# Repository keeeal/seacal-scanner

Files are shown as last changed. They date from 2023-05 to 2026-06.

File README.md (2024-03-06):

# SEACAL Scanner
A 3D printable photogrammetry scanner for the Southeast Asian Ceramics Archaeology Laboratory.





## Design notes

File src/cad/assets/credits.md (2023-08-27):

# axle-screw
 - Phil Barrenger (philbarrenger)
 - https://www.thingiverse.com/thing:1657541
# phone-clamp
 - Ryan Huang (HeyVye)
 - https://www.thingiverse.com/thing:4619937
# gopro-bolt
 - Ryan Huang (HeyVye)
 - https://www.thingiverse.com/thing:3774977

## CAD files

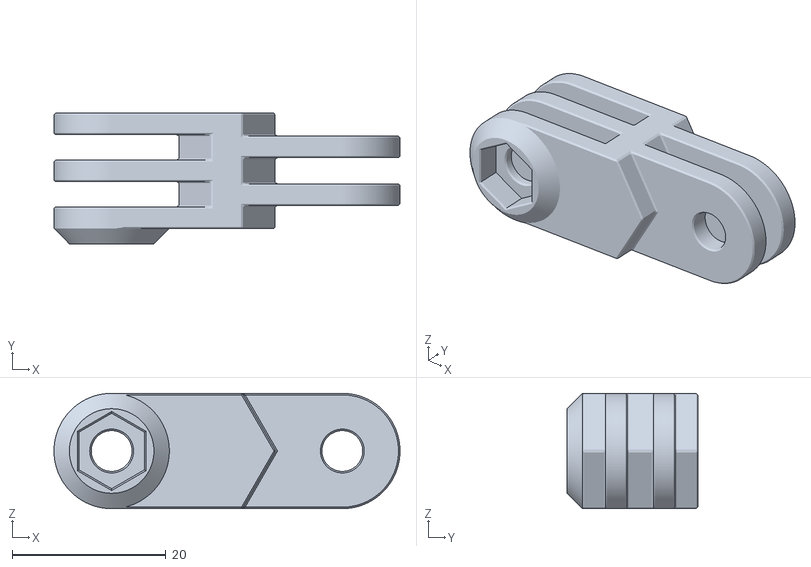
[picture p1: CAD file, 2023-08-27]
src/cad/assets/phone-clamp/clamp-extender.stl
45.0 x 17.0 x 15.0

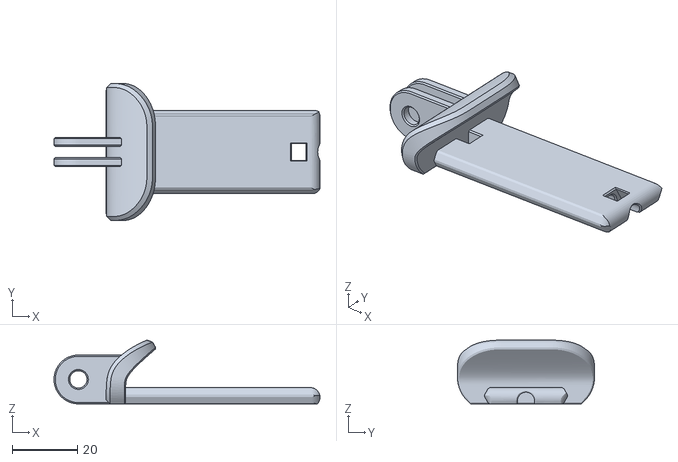
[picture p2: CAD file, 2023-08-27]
src/cad/assets/phone-clamp/clamp-b.stl
81.5 x 42.0 x 19.6

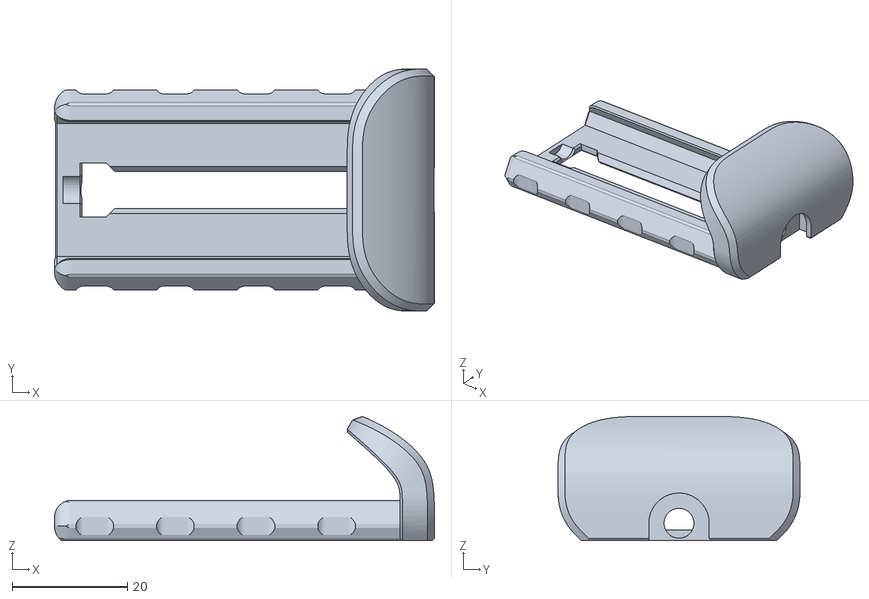
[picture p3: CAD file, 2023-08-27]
src/cad/assets/phone-clamp/clamp-a.stl
66.0 x 42.0 x 21.6

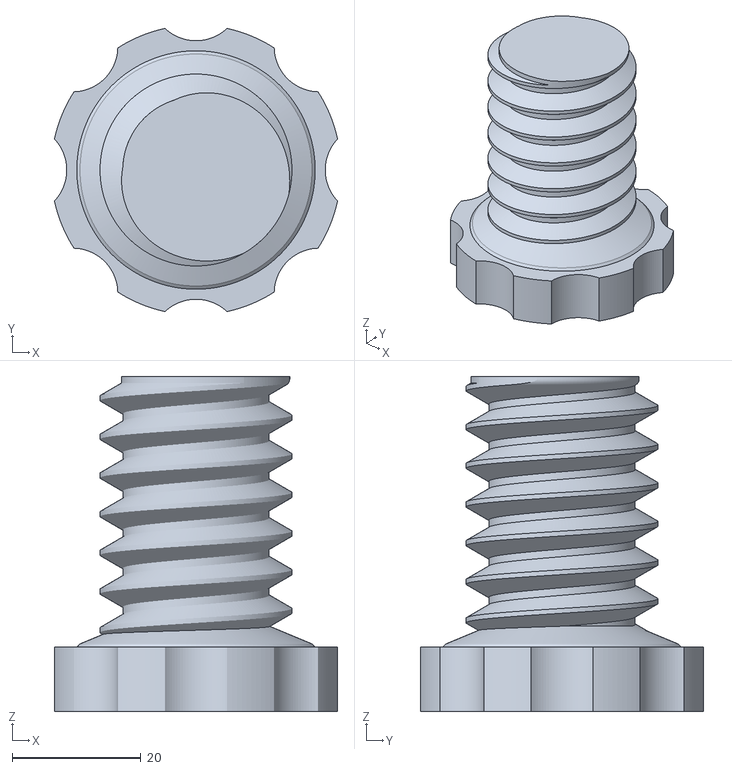
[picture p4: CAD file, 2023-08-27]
src/cad/assets/axle-screw.stl
44.0 x 44.0 x 52.0

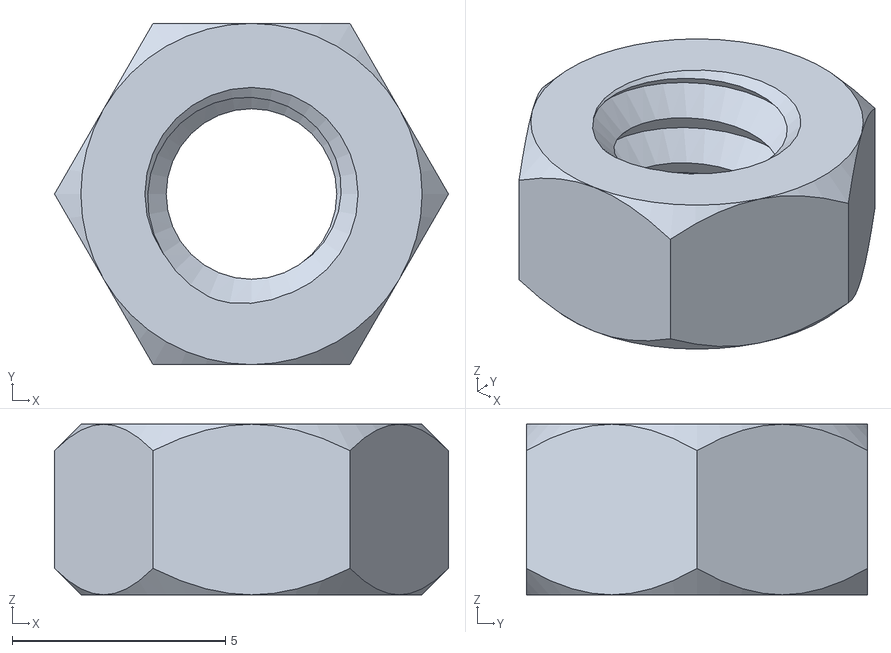
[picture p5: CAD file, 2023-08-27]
src/cad/assets/gopro-bolt/gopro-nut.stl
9.24 x 8.00 x 4.00

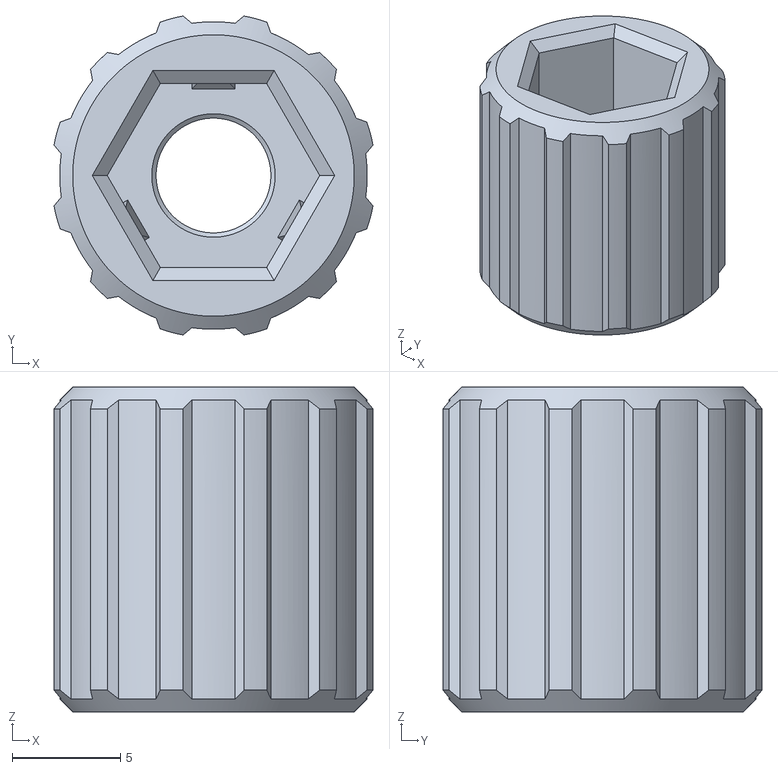
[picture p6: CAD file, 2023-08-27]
src/cad/assets/gopro-bolt/gopro-knob.stl
14.7 x 14.7 x 15.0

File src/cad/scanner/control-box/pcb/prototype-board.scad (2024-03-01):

use <../../../utils/shapes/2d/rounded-square.scad>
use <dupont.scad>

EPS = 1e-3;

module prototype_board()
{
    color([ 0.4, 0.1, 0.1 ]) linear_extrude(1.5)
    {
        rounded_square([ 66, 53.5 ], r = 1, center = true, $fn = 4);
        translate([ 33, -4 ]) rounded_square([ 5 + EPS, 39 ], r = 2.5, center = true, $fn = 4);
    }
}

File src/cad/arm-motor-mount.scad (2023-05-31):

// clang-format off

use <utils/shapes/2d/rounded-square.scad>

$fn = 32;

// clang-format on

module tube_mount()
{
    difference()
    {
        union()
        {
            linear_extrude(47, center = true) rounded_square(30.2, r = 1.8, center = true);
            translate([ -30.2 / 4, 0, 0 ]) linear_extrude(47, center = true) square([ 30.2 / 2, 30.2 ], center = true);
        }

        linear_extrude(62, center = true) rounded_square(27, r = 1, center = true);
    }
    for (n = [-1:1])
        translate([ 0, 0, n * 12 ]) for (i = [0:3]) rotate(90 * i) hull()
        {
            translate([ -5, 14, -4 ]) sphere(0.5);
            translate([ 5, 14, -4 ]) sphere(0.5);
            translate([ -5, 13.2, 0 ]) sphere(0.5);
            translate([ 5, 13.2, 0 ]) sphere(0.5);
            translate([ -5, 14, +4 ]) sphere(0.5);
            translate([ 5, 14, +4 ]) sphere(0.5);
        }
}

module nema_mount()
{
    difference()
    {
        translate([ 0, 0, 0 ]) linear_extrude(30.2) union()
        {
            rounded_square([ 47, 47 ], r = 4, center = true, $fn = 4);
            translate([ 0, -47 / 4 ]) square([ 47, 47 / 2 ], center = true);
        }
        translate([ 0, 0, -2 ]) linear_extrude(30.2) rounded_square([ 43, 43 ], r = 5, center = true);
        translate([ 0, 0, -1 ]) cylinder(100, r = 12);
        for (i = [ 0, 1, 2, 3 ])
            rotate([ 0, 0, i * 90 ]) translate([ 31.04 / 2, 31.04 / 2, 0 ]) cylinder(100, d = 4);
    }
}

module arm_motor_mount()
{
    rotate([ 0, 90, 0 ]) tube_mount();
    difference()
    {
        translate([ 0, 15.1, 38.5 ]) rotate([ 90, 0, 0 ]) nema_mount();
        translate([ 0, 15, 38.5 ]) cube([ 100, 16, 18 ], center = true);
    }
}

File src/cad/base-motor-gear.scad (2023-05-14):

// clang-format off
use <utils/gears/herringbone.scad>
use <utils/gears/simple.scad>

$fn = 32;
// clang-format on

module base_motor_gear(tol_x = .2, tol_z = .4)
{
    difference()
    {
        union()
        {
            herringbone_gear(10, 12, -32);
            cylinder(20, r = 5);
        }
        translate([ 0, 0, -1 ]) linear_extrude(100) difference()
        {
            circle(2.5 + tol_x);
            translate([ 7 + tol_x, 0 ]) square([ 10, 10 ], true);
        }
    }
}

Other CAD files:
src/cad/assets/phone-clamp/clamp-nut.stl
src/cad/parts/arm-motor-mount.scad
src/cad/__assembly__.scad
src/cad/apex.scad
src/cad/axle.scad
src/cad/badge.scad
src/cad/base.scad
src/cad/bearing-gear.scad
src/cad/cap.scad
src/cad/components/aluminium-tube.scad
src/cad/components/stop-button.scad
src/cad/corner.scad
src/cad/foot.scad
src/cad/gopro-mount.scad
src/cad/parts/apex.scad
src/cad/parts/axle.scad
src/cad/parts/badge.scad
src/cad/parts/base-motor-gear.scad
src/cad/parts/base.scad
src/cad/parts/bearing-gear.scad
src/cad/parts/foot.scad
src/cad/parts/gopro-mount.scad
src/cad/scanner/__subassembly__.scad
src/cad/scanner/arm/aluminium-tube.scad
src/cad/scanner/arm/axle.scad
src/cad/scanner/arm/gopro-mount.scad
src/cad/scanner/control-box/__subassembly__.scad
src/cad/scanner/control-box/box/__subassembly__.scad
src/cad/scanner/control-box/box/box-without-components.scad
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

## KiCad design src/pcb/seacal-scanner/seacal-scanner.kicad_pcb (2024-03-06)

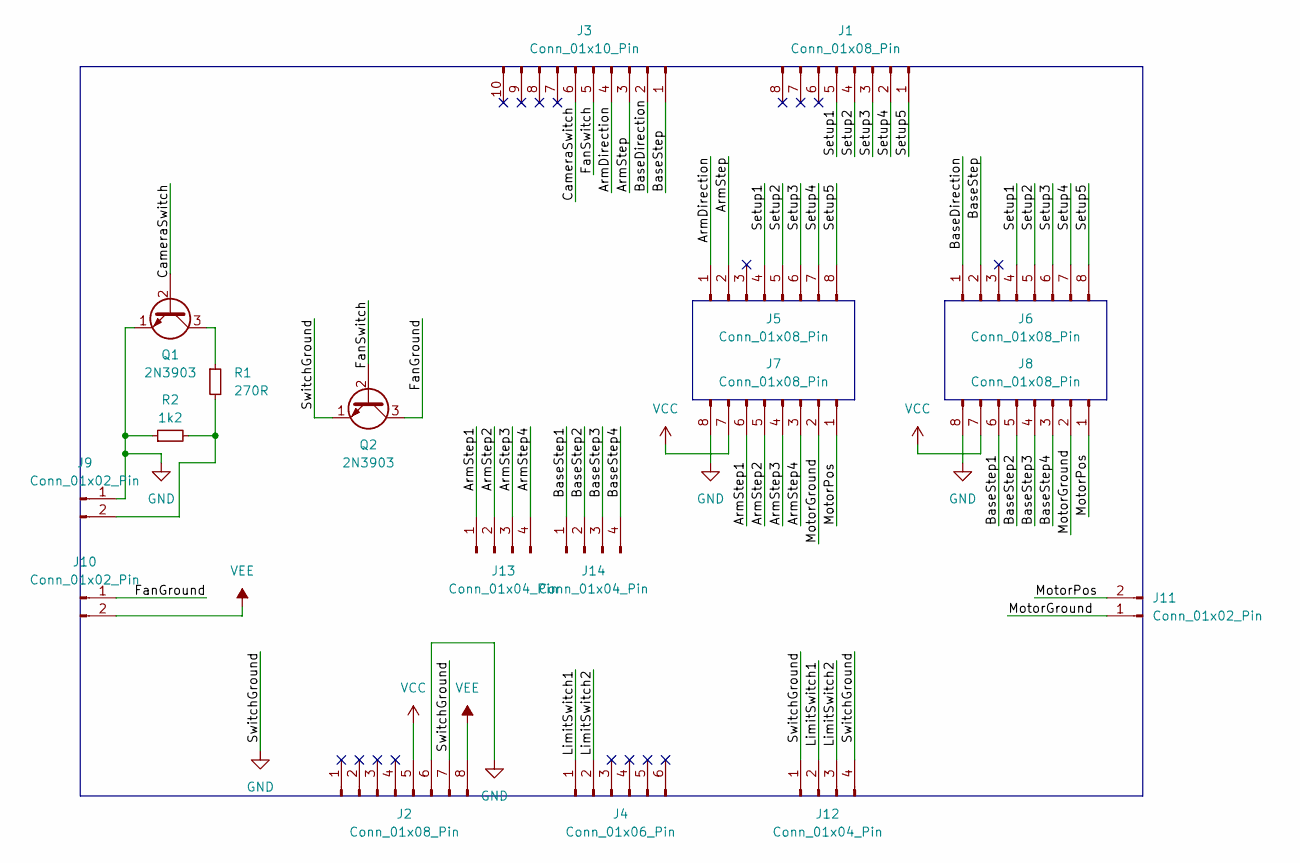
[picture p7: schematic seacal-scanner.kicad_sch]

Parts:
J1, J2, J5, J6, J7, J8: Conn_01x08_Pin; PinHeader_1x08_P2.54mm_Vertical
J3: Conn_01x10_Pin; PinHeader_1x10_P2.54mm_Vertical
J4: Conn_01x06_Pin; PinHeader_1x06_P2.54mm_Vertical
J9, J10, J11: Conn_01x02_Pin; PinHeader_1x02_P2.54mm_Vertical
J12, J13, J14: Conn_01x04_Pin; PinHeader_1x04_P2.54mm_Vertical
Q1, Q2: 2N3903; TO-92_Inline
R1: 270R; R_Axial_DIN0207_L6.3mm_D2.5mm_P10.16mm_Horizontal
R2: 1k2; R_Axial_DIN0207_L6.3mm_D2.5mm_P10.16mm_Horizontal

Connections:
/ArmDirection: J3.4, J5.1
/ArmStep: J3.3, J5.2
/ArmStep1: J7.6, J13.1
/ArmStep2: J7.5, J13.2
/ArmStep3: J7.4, J13.3
/ArmStep4: J7.3, J13.4
/BaseDirection: J3.2, J6.1
/BaseStep: J3.1, J6.2
/BaseStep1: J8.6, J14.1
/BaseStep2: J8.5, J14.2
/BaseStep3: J8.4, J14.3
/BaseStep4: J8.3, J14.4
/CameraSwitch: J3.6, Q1.2 (B)
/FanGround: J10.1, Q2.3 (C)
/FanSwitch: J3.5, Q2.2 (B)
/LimitSwitch1: J4.1, J12.2
/LimitSwitch2: J4.2, J12.3
/MotorGround: J7.2, J8.2, J11.1
/MotorPos: J7.1, J8.1, J11.2
/Setup1: J1.5, J5.4, J6.4
/Setup2: J1.4, J5.5, J6.5
/Setup3: J1.3, J5.6, J6.6
/Setup4: J1.2, J5.7, J6.7
/Setup5: J1.1, J5.8, J6.8
GND: J2.6, J2.7, J7.8, J8.8, J9.1, J12.1, J12.4, Q1.1 (E), Q2.1 (E), R2.1
unnamed: J9.2, R1.2, R2.2
unnamed: Q1.3 (C), R1.1
VCC: J2.5, J7.7, J8.7
VEE: J2.8, J10.2

Board: 2 copper layers, 18 parts (0 on the bottom side), 29 nets, no tracks yet.

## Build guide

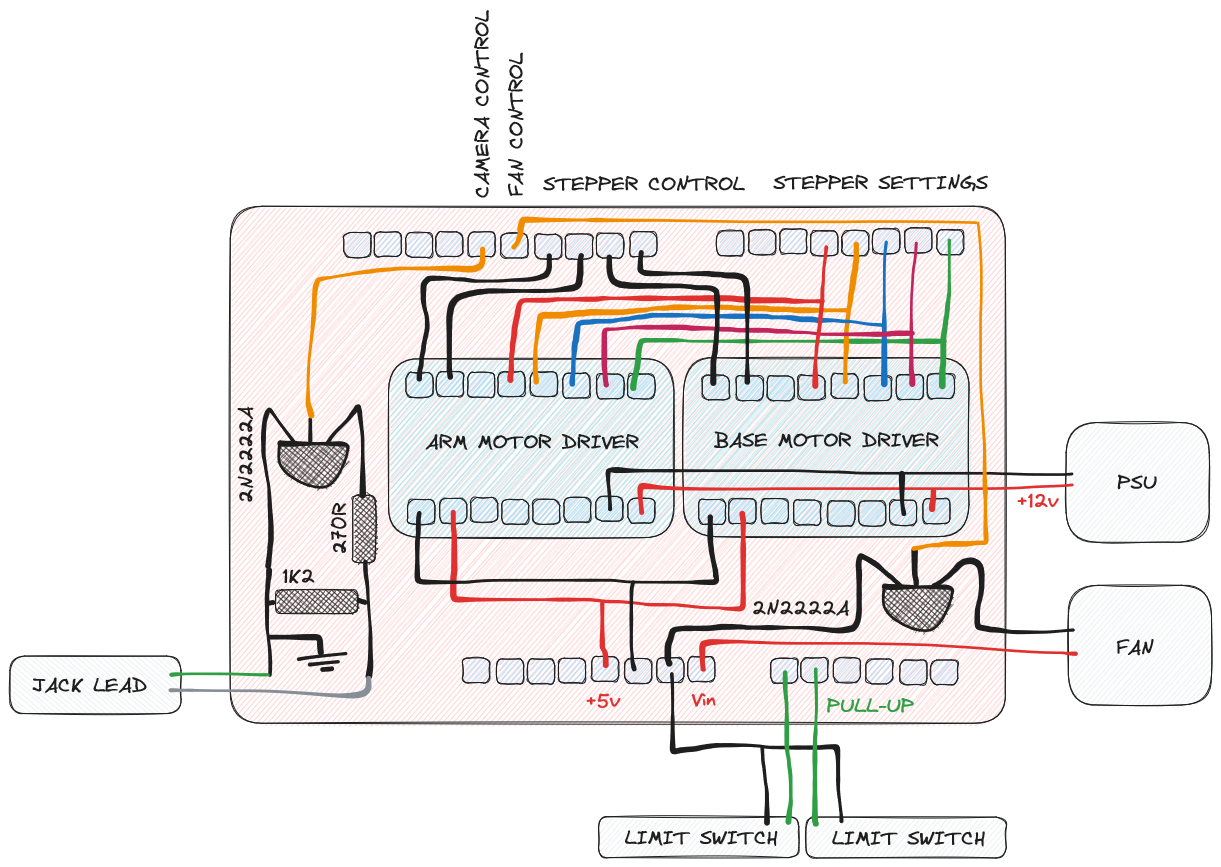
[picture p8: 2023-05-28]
assets/wiring-diagram/wiring-diagram.png

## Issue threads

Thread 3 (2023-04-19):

Design camera arm joints

keeeal, 2023-04-19:
Blocked by #15

Includes
 - basic push-fit joints
 - joints with legs
 - swivel joints at apex

Closed 2023-04-28.

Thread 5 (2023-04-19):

Add smooth acceleration option to stepper motor control

keeeal, 2023-04-19:
Blocked by #11

keeeal, 2023-04-30:
https://docs.arduino.cc/learn/electronics/stepper-motors Use Stepper.h instead of writing speed logic from scratch.

keeeal, 2023-05-03:
https://youtu.be/jsXolwJskKM motion filtering

keeeal, 2023-05-03:
https://learn.adafruit.com/multi-tasking-the-arduino-part-1/overview Do not use delays

keeeal, 2023-05-13:
www.airspayce.com/mikem/arduino/AccelStepper/ There is a library for this

Closed 2023-08-27.

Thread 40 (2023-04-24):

Replace firmware workflow with docker image

keeeal, 2023-04-24:
Docker image must contain `arduino-cli`. This will allow local reproducible builds.

Also make firmware the default make target.

Closed 2023-04-24.

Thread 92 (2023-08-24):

Extend feet to accomodate arm

keeeal, 2023-08-24:
- Arm collides with frame when at its lowest point
- Frame must be narrower

=> redesign feet to allow frame to push into them further

Closed 2023-08-27.

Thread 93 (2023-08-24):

Grip arm in axle better

keeeal, 2023-08-24:
- arm slides in push fit axle piece
- push fit is tight enough at first but seems to loosen over time

=> add threaded hole and large printed bolt... or something better?

Closed 2023-08-27.

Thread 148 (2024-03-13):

Fix driver footprints

keeeal, 2024-03-13:

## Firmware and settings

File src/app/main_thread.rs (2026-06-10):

use std::collections::VecDeque;
use std::env::consts::OS;
use std::path::Path;
use std::sync::mpsc::channel;
use std::sync::mpsc::TryRecvError;
use std::sync::{Arc, Mutex};
use std::thread;
use std::time::Duration;

use eframe::egui;

use crate::camera;
use crate::camera::Camera;
use crate::message::Message;
use crate::{read_thread, write_thread};
use crate::{CaptureState, LogLevel, State};

const SERIAL_BAUD: u32 = 115200;

// #[derive(Debug, Clone)]
struct Position {
    index: u32,
    base: f64,
    arm: f64,
    photo: bool,
}

impl Position {
    fn to_scanner_coordinates(&self) -> (u32, u32) {
        ((self.base * 1024.) as u32, (self.arm * 1024.) as u32)
    }

    fn to_degrees(&self) -> (f64, f64) {
        ((self.base * 360.) % 360., (self.arm * 150.) - 60.)
    }
}

fn generate_positions(
    num_photos: u32,
    num_revolutions: f64,
    spiral_pattern: bool,
    start_height: f64,
    stop_height: f64,
) -> Vec<Position> {
    if num_photos == 0 {
        return Vec::new();
    }
    let mut positions = Vec::new();
    for index in 0..num_photos {
        let mut fraction = (index + 1) as f64 / num_photos as f64;
        let base_position = fraction * num_revolutions;
        if !spiral_pattern {
            fraction = base_position.floor() / num_revolutions;
        }
        let arm_position = fraction * (stop_height - start_height) + start_height;
        positions.push(Position {
            index,
            base: base_position,
            arm: arm_position,
            photo: true,
        });
    }
    positions.push(Position {
        index: num_photos,
        base: positions.last().unwrap().base,
        arm: 0.,
        photo: false,
    });
    positions
}

pub fn spawn(state: Arc<Mutex<State>>, context: egui::Context) {
    let log = |level: LogLevel, message: String| {
        state.lock().unwrap().log(level, message);
        context.request_repaint();
    };
    let log_if_quiet_for = |duration: Duration, level: LogLevel, message: String| {
        state
            .lock()
            .unwrap()
            .log_if_quiet_for(duration, level, message);
        context.request_repaint();
    };

    let port_prefix = if OS == "windows" {
        "COM"
    } else if OS == "linux" {
        "/dev/ttyACM"
    } else {
        panic!("Unsupported OS");
    };

    let read_port = Arc::new(Mutex::new(None));
    let write_port = Arc::new(Mutex::new(None));
    let read_port_clone = read_port.clone();
    let write_port_clone = write_port.clone();
    let (read_sender, read_receiver) = channel::<Message>();
    let (write_sender, write_receiver) = channel::<Message>();
    thread::spawn(|| read_thread::spawn(read_port_clone, read_sender));
    thread::spawn(|| write_thread::spawn(write_port_clone, write_receiver));

    let mut last_arm_speed: u8 = 100;
    let mut last_base_speed: u8 = 100;
    let mut move_to = |coordinates: (u32, u32)| {
        let arm_speed = state.lock().unwrap().arm_speed;
        let base_speed = state.lock().unwrap().base_speed;
        if arm_speed != last_arm_speed || base_speed != last_base_speed {
            write_sender
                .send(Message::SetSpeed((base_speed, arm_speed)))
                .unwrap();
            last_arm_speed = arm_speed;
            last_base_speed = base_speed;
            println!("Set speed to ({}, {})", base_speed, arm_speed);
            thread::sleep(Duration::from_millis(100));
        }
        write_sender.send(Message::MoveTo(coordinates)).unwrap();
    };

    let mut camera: Option<Camera> = None;
    let mut position_queue: VecDeque<Position> = VecDeque::new();
    let mut object_directory: Option<String> = None;

    loop {
        if state.lock().unwrap().refresh_clicked {
            state.lock().unwrap().refresh_clicked = false;
            match camera::list() {
                Ok(cameras) => state.lock().unwrap().all_cameras = cameras,
                Err(error) => state
                    .lock()
                    .unwrap()
                    .log(LogLevel::Error, format!("{}", error)),
            }
        }
        if state.lock().unwrap().test_clicked {
            state.lock().unwrap().test_clicked = false;
            let selected_camera = state.lock().unwrap().selected_camera.clone();
            camera = match camera::setup(selected_camera) {
                Ok(camera) => Some(camera),
                Err(error) => {
                    log(LogLevel::Error, format!("{}", error));
                    continue;
                }
            };
            if let Some(ref mut camera) = camera {
                let save_directory = state.lock().unwrap().save_directory.clone();
                let path = format!("{}/TEST.jpg", save_directory.to_str().unwrap());
                match camera::save_photo(camera, Path::new(&path)) {
                    Ok(buffer) => log(
                        LogLevel::Success,
                        format!("Saved to {} ({})", path, buffer.resolution()),
                    ),
                    Err(error) => log(LogLevel::Error, format!("{}", error)),
                }
            }
        }
        if read_port.lock().unwrap().is_none() || write_port.lock().unwrap().is_none() {
            *read_port.lock().unwrap() = None;
            *write_port.lock().unwrap() = None;

            log_if_quiet_for(
                Duration::from_secs(2),
                LogLevel::Warning,
                "Searching for device".to_string(),
            );
            let ports = serialport::available_ports().unwrap_or_default();
            for info in ports {
                if !info.port_name.starts_with(port_prefix) {
                    continue;
                }
                let port = match serialport::new(&info.port_name, SERIAL_BAUD)
                    .dtr_on_open(true)
                    .timeout(Duration::from_millis(10))
                    .open()
                {
                    Ok(port) => port,
                    Err(_) => continue,
                };
                match port.clear(serialport::ClearBuffer::All) {
                    Ok(()) => {}
                    Err(_) => {
                        continue;
                    }
                }
                *read_port.lock().unwrap() = Some(port.try_clone().unwrap());
                *write_port.lock().unwrap() = Some(port);

                // Ping the device and wait for a pong response
                write_sender.send(Message::Ping).unwrap();
                match read_receiver.recv_timeout(Duration::from_secs(1)) {
                    Ok(Message::Pong) => {
                        log(LogLevel::Success, "Connected".to_string());
                        continue;
                    }
                    _ => {
                        *read_port.lock().unwrap() = None;
                        *write_port.lock().unwrap() = None;
                        continue;
                    }
                }
            }
            thread::sleep(Duration::from_millis(100));
        } else {
            match read_receiver.try_recv() {
                Ok(Message::MoveComplete(reported_coordinates)) => {
                    println!("Scanner is at {:?}", reported_coordinates);
                    if position_queue.front().is_none() {
                        log(
                            LogLevel::Warning,
                            format!("Unexpected position: {:?}", reported_coordinates),
                        );
                        continue;
                    }
                    let current_position = position_queue.front().unwrap();
                    let current_coordinates = current_position.to_scanner_coordinates();
                    if reported_coordinates != current_coordinates {
                        log(
                            LogLevel::Warning,
                            format!(
                                "Expected position {:?}, got {:?}",
                                current_coordinates, reported_coordinates
                            ),
                        );
                        if state.lock().unwrap().capture_state != CaptureState::Paused {
                            move_to(current_coordinates);
                        }
                        continue;
                    }
                    if current_position.photo {
                        let (base_degrees, arm_degrees) = current_position.to_degrees();
                        if let Some(ref mut camera) = camera {
                            let save_directory = state.lock().unwrap().save_directory.clone();
                            let object_name = state.lock().unwrap().object_name.clone();
                            let photos_per_position = state.lock().unwrap().photos_per_position;
                            let shutter_delay = state.lock().unwrap().shutter_delay;
                            if object_directory.is_none() {
                                object_directory = Some(
                                    format!("{}/{}", save_directory.to_str().unwrap(), object_name)
                                        .to_string(),
                                )
                            }
                            for index in 0..photos_per_position {
                                thread::sleep(Duration::from_millis(shutter_delay as u64));
                                let path = format!(
                                    "{}/{}_{:.1}deg_{:.1}deg{}.jpg",
                                    object_directory.as_ref().unwrap(),
                                    current_position.index,
                                    base_degrees,
                                    arm_degrees,
                                    if photos_per_position > 1 {
                                        format!(".{}", index + 1)
                                    } else {
                                        "".to_string()
                                    }
                                );
                                match camera::save_photo(camera, Path::new(&path)) {
                                    Ok(buffer) => log(
                                        LogLevel::Success,
                                        format!("Saved to {} ({})", path, buffer.resolution()),
                                    ),
                                    Err(error) => log(LogLevel::Error, format!("{}", error)),
                                }
                            }
                        }
                    }
                    state.lock().unwrap().progress = (current_position.index + 1) as f32
                        / (position_queue.back().unwrap().index + 1) as f32;
                    position_queue.pop_front();
                    if let Some(next_position) = position_queue.front() {
                        if state.lock().unwrap().capture_state != CaptureState::Paused {
                            move_to(next_position.to_scanner_coordinates());
                        }
                    } else {
                        write_sender.send(Message::DisableSteppers).unwrap();
                        object_directory = None;
                        state.lock().unwrap().capture_state = CaptureState::Idle;
                    }
                    context.request_repaint();
                }
                Ok(Message::StartPressed) => {
                    state.lock().unwrap().capture_clicked = true;
                }
                Ok(Message::StopPressed) => {
                    log(LogLevel::Error, "Emergency stop activated".to_string());
                    position_queue.clear();
                    state.lock().unwrap().capture_state = CaptureState::Stopped;
                    state.lock().unwrap().progress = 0.;
                    context.request_repaint();
                }
                Ok(Message::StopReleased) => {
                    log(LogLevel::Info, "Emergency stop released".to_string());
                    position_queue.clear();
                    state.lock().unwrap().capture_state = CaptureState::Idle;
                    state.lock().unwrap().progress = 0.;
                    context.request_repaint();
                }
                Ok(Message::HomingInProgress) => {
                    log(LogLevel::Info, "Homing in progress".to_string())
                }
                Ok(Message::HomingError) => log(LogLevel::Error, "Homing Error".to_string()),
                Ok(Message::UnexpectedMsg(discriminant)) => log(
                    LogLevel::Warning,
                    format!("[CTRL] Unexpected message: {:X}", discriminant),
                ),
                Ok(message) => log(
                    LogLevel::Warning,
                    format!("[APP] Unexpected message: {:?}", message),
                ),
                Err(TryRecvError::Disconnected) => {
                    *read_port.lock().unwrap() = None;
                    *write_port.lock().unwrap() = None;
                    continue;
                }
                Err(TryRecvError::Empty) => {}
            }
            if state.lock().unwrap().capture_clicked {
                state.lock().unwrap().capture_clicked = false;
                let capture_state = state.lock().unwrap().capture_state.clone();
                let selected_camera = state.lock().unwrap().selected_camera.clone();
                let num_photos = state.lock().unwrap().num_photos;
                let num_revolutions = state.lock().unwrap().num_revolutions;
                let spiral_pattern = state.lock().unwrap().spiral_pattern;
                let start_height = state.lock().unwrap().start_height;

                match capture_state {
                    CaptureState::Idle => {
                        position_queue.clear();
                        camera = match camera::setup(selected_camera) {
                            Ok(camera) => Some(camera),
                            Err(error) => {
                                log(LogLevel::Error, format!("{}", error));
                                continue;
                            }
                        };

                        println!("Camera set");

                        position_queue.extend(generate_positions(
                            num_photos,
                            num_revolutions as f64,
                            spiral_pattern,
                            start_height as f64 / 100.,
                            1.0, // Stop height is not implemented in UI
                        ));
                        thread::sleep(Duration::from_millis(100));
                        if let Some(next_position) = position_queue.front() {
                            state.lock().unwrap().capture_state = CaptureState::InProgress;
                            write_sender.send(Message::ZeroBase).unwrap();
                            move_to(next_position.to_scanner_coordinates());
                        }
                    }
                    CaptureState::InProgress => {
                        state.lock().unwrap().capture_state = CaptureState::Paused;
                    }
                    CaptureState::Paused => {
                        if let Some(next_position) = position_queue.front() {
                            state.lock().unwrap().capture_state = CaptureState::InProgress;
                            move_to(next_position.to_scanner_coordinates());
                        } else {
                            state.lock().unwrap().capture_state = CaptureState::Idle;
                        }
                    }
                    CaptureState::Stopped => {}
                }
                context.request_repaint();
            }
        }
    }
}

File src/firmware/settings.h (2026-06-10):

#pragma once

#define SERIAL_BAUD 115200

// Output pins
#define ARM_STEP_PIN D8
#define ARM_DIR_PIN D9
#define BASE_STEP_PIN D10
#define BASE_DIR_PIN D11
#define FAN_PIN D12
#define GREEN_LED_PIN D6
#define RED_LED_PIN D7
#define ENABLE_PIN D0
#define RESET_PIN D4
#define MS1_PIN D1
#define MS2_PIN D2
#define MS3_PIN D3

// Input pins
#define TOP_LIMIT_PIN A0
#define BOTTOM_LIMIT_PIN A1
#define START_BUTTON_PIN A2
#define STOP_BUTTON_PIN A3

// Global settings
#define NUM_BASE_STEPS 74666 // Steps per base rotation
#define INIT_BASE_SPEED 8192 // Steps per second
#define INIT_ARM_SPEED 8192  // Steps per second

// Homing settings
#define HOMING_SPEED_COARSE 4096 // Steps per second
#define HOMING_SPEED_FINE 128    // Steps per second

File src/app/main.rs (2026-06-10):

#![cfg_attr(not(debug_assertions), windows_subsystem = "windows")]

mod camera;
mod interface;
mod main_thread;
mod message;
mod read_thread;
mod write_thread;

use std::collections::HashMap;
use std::path::PathBuf;
use std::sync::{Arc, Mutex};
use std::thread;
use std::time::{Duration, Instant};

use chrono::Local;
use directories::UserDirs;
use egui_file_dialog::FileDialog;

#[derive(Debug, Clone)]
pub enum LogLevel {
    Error,
    Warning,
    Info,
    Success,
}

#[derive(Debug, Clone, PartialEq)]
pub enum CaptureState {
    Idle,
    InProgress,
    Paused,
    Stopped,
}

pub struct State {
    pub object_name: String,
    pub all_cameras: HashMap<camera::Index, camera::Info>,
    pub selected_camera: Option<camera::Index>,
    pub test_clicked: bool,
    pub refresh_clicked: bool,
    pub num_photos: u32,
    pub num_revolutions: u32,
    pub spiral_pattern: bool,
    pub arm_speed: u8,
    pub invert_arm: bool,
    pub base_speed: u8,
    pub invert_base: bool,
    pub start_height: u8,
    pub photos_per_position: u32,
    pub shutter_delay: u32,
    pub save_directory_dialog: FileDialog,
    pub save_directory: PathBuf,
    pub capture_clicked: bool,
    pub capture_state: CaptureState,
    pub progress: f32,
    pub log_message: String,
    pub log_level: LogLevel,
    pub log_time: Option<Instant>,
}

impl Default for State {
    fn default() -> Self {
        Self {
            object_name: Local::now().format("%Y-%m-%d-%H-%M-%S").to_string(),
            all_cameras: camera::list().unwrap(),
            selected_camera: None,
            test_clicked: false,
            refresh_clicked: false,
            num_photos: 100,
            num_revolutions: 5,
            spiral_pattern: false,
            arm_speed: 100,
            invert_arm: false,
            base_speed: 100,
            invert_base: false,
            start_height: 0,
            photos_per_position: 1,
            shutter_delay: 0,
            save_directory_dialog: FileDialog::new(),
            save_directory: UserDirs::new()
                .unwrap()
                .picture_dir()
                .unwrap()
                .to_path_buf(),
            capture_clicked: false,
            capture_state: CaptureState::Idle,
            progress: 0.0,
            log_message: String::new(),
            log_level: LogLevel::Info,
            log_time: None,
        }
    }
}

impl State {
    pub fn log(&mut self, level: LogLevel, message: String) {
        println!("[{}] {:?}: {}", Local::now(), level, message);
        self.log_message = message;
        self.log_level = level;
        self.log_time = Some(Instant::now());
    }

    pub fn log_if_quiet_for(&mut self, duration: Duration, level: LogLevel, message: String) {
        if self.log_time.is_none() || duration < Instant::now() - self.log_time.unwrap() {
            self.log(level, message);
        }
    }

    pub fn reset_object_name(&mut self) {
        self.object_name = Local::now().format("%Y-%m-%d-%H-%M-%S").to_string();
    }
}

#[derive(Default)]
struct App {
    state: Arc<Mutex<State>>,
}

impl App {
    fn new(creation_context: &eframe::CreationContext<'_>) -> Self {
        egui_extras::install_image_loaders(&creation_context.egui_ctx);
        interface::initialize(creation_context);

        let app = Self::default();
        let state = app.state.clone();
        let context = creation_context.egui_ctx.clone();
        thread::spawn(|| main_thread::spawn(state, context));
        app
    }
}

fn main() -> eframe::Result {
    eframe::run_native(
        "",
        interface::options(),
        Box::new(|creation_context| Ok(Box::new(App::new(creation_context)))),
    )
}

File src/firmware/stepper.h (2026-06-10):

#pragma once

namespace stepper
{

class Settings
{
  public:
    enum class StepMode
    {
        STANDBY,
        FULL_STEP,
        HALF_STEP_A,
        HALF_STEP_B,
        QUARTER_STEP,
        EIGHTH_STEP,
        SIXTEENTH_STEP,
        THIRTY_SECOND_STEP,
    };

    Settings(pin_size_t enable_pin, pin_size_t ms1_pin, pin_size_t ms2_pin,
             pin_size_t ms3_pin, pin_size_t reset_pin);

    void begin();
    void enable();
    void disable();
    void setStepMode(StepMode step_mode);
    void reset();
    void cancelReset();

  private:
    pin_size_t _enable_pin;
    pin_size_t _ms1_pin;
    pin_size_t _ms2_pin;
    pin_size_t _ms3_pin;
    pin_size_t _reset_pin;
};

Settings::Settings(pin_size_t enable_pin, pin_size_t ms1_pin,
                   pin_size_t ms2_pin, pin_size_t ms3_pin, pin_size_t reset_pin)
    : _enable_pin(enable_pin), _ms1_pin(ms1_pin), _ms2_pin(ms2_pin),
      _ms3_pin(ms3_pin), _reset_pin(reset_pin)
{
}

void Settings::begin()
{
    pinMode(_enable_pin, OUTPUT);
    pinMode(_ms1_pin, OUTPUT);
    pinMode(_ms2_pin, OUTPUT);
    pinMode(_ms3_pin, OUTPUT);
    pinMode(_reset_pin, OUTPUT);

    disable();
    setStepMode(StepMode::STANDBY);
    cancelReset();
}

void Settings::enable()
{
    digitalWrite(_enable_pin, LOW);
}

void Settings::disable()
{
    digitalWrite(_enable_pin, HIGH);
}

void Settings::setStepMode(StepMode step_mode)
{
    switch (step_mode)
    {
    case StepMode::STANDBY:
        digitalWrite(_ms1_pin, LOW);
        digitalWrite(_ms2_pin, LOW);
        digitalWrite(_ms3_pin, LOW);
        break;
    case StepMode::FULL_STEP:
        digitalWrite(_ms1_pin, LOW);
        digitalWrite(_ms2_pin, LOW);
        digitalWrite(_ms3_pin, HIGH);
        break;
    case StepMode::HALF_STEP_A:
        digitalWrite(_ms1_pin, LOW);
        digitalWrite(_ms2_pin, HIGH);
        digitalWrite(_ms3_pin, LOW);
        break;
    case StepMode::HALF_STEP_B:
        digitalWrite(_ms1_pin, HIGH);
        digitalWrite(_ms2_pin, LOW);
        digitalWrite(_ms3_pin, LOW);
        break;
    case StepMode::QUARTER_STEP:
        digitalWrite(_ms1_pin, LOW);
        digitalWrite(_ms2_pin, HIGH);
        digitalWrite(_ms3_pin, HIGH);
        break;
    case StepMode::EIGHTH_STEP:
        digitalWrite(_ms1_pin, HIGH);
        digitalWrite(_ms2_pin, LOW);
        digitalWrite(_ms3_pin, HIGH);
        break;
    case StepMode::SIXTEENTH_STEP:
        digitalWrite(_ms1_pin, HIGH);
        digitalWrite(_ms2_pin, HIGH);
        digitalWrite(_ms3_pin, LOW);
        break;
    case StepMode::THIRTY_SECOND_STEP:
        digitalWrite(_ms1_pin, HIGH);
        digitalWrite(_ms2_pin, HIGH);
        digitalWrite(_ms3_pin, HIGH);
        break;
    }
}

// Locks motor to the nearest full step
void Settings::reset()
{
    digitalWrite(_reset_pin, HIGH);
}

void Settings::cancelReset()
{
    digitalWrite(_reset_pin, LOW);
}

} // namespace stepper

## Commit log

2023-04-01 repo structure
    [2d.scad, 3d.scad, gears.scad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]
2023-04-01 add base
    [2d.scad, main.scad, nema17.scad]
2023-04-01 squircular base
    [main.scad]
2023-04-03 use herringbone gears
    [main.scad]
2023-04-18 add workflow
    [main.scad]
2023-04-19 fix firmware workflow
    [2d.scad, 3d.scad, gears.scad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]
2023-04-22 Adjust base-to-lazy-susan mounting holes (#32)
    [main.scad]
2023-04-24 Submodule `cad/utils` (#42)
    * submodule utils
    * checkout with submodules recursive
    [2d.scad, 3d.scad, gears.scad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]
2023-04-28 Design camera arm joints (#52)
    * add foot
    * add apex
    * add axle
    * add corner
    * add cap
    * --hardwarnings on
    [main.scad]
2023-04-30 Split monolithic scad file into parts (#53)
    * restructure
    [__assembly__.scad, apex.scad, axle.scad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]
2023-05-14 Format openscad code (#60)
    * Create format service
    * combine format checks
    * rename jobs
    [__assembly__.scad, apex.scad, axle.scad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]
2023-05-28 Check that a single volume is created per STL (#64)
    * archive STL build logs
    * use pytest
    * add cad tests
2023-05-28 Add gopro mount to attach a phone (#61)
    * Add gopro mount
    * update openscad utils
    [gopro-mount.scad]
2023-05-28 Add arm motor mount (#65)
    * add arm motor mount
    * format
    [arm-motor-mount.scad]
2023-05-28 Add wiring diagram (#66)
    * add wiring diagram
    * only check format on code change
2023-05-28 Widen base (#67)
    * widen base
    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
    [base.scad]
2023-05-28 Add badge (#68)
    * Add badge
    * gopro-mount $fn = 32
    [badge.scad, base.scad, gopro-mount.scad]
2023-05-29 update assembly (#72)
    [__assembly__.scad, arm-motor-mount.scad, gopro-mount.scad]
2023-05-31 Add connector holes to arm motor mount (#77)
    [arm-motor-mount.scad]
2023-06-08 Separate parts and components (#81)
    * separate parts + components dirs
    * fix tests
    * test_at_least_one_scad_file
    [aluminium-tube.scad, apex.scad, arm-motor-mount.scad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]
2023-06-09 Add stop button (#82)
    [main.scad, stop-button.scad]
2023-06-12 Openscad recursive build system (#85)
    * add recursive build system
    * fix utils references
    * update gitignore
    * add structure tests
    * update parts file
    * format tests
    [__subassembly__.scad, aluminium-tube.scad, apex.scad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]
2023-08-13 Design control box (#86)
    * gx12 gx16 led-indicator limit-switch start-button
    * test for uniqueness
    * add control box
    * test_no_fn_usage
    * add $fn to customizer
    * remove $fn
    * update parts yaml
    * finish pcb
    * update box and lid
    * fix firmware archive
    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
    [__subassembly__.scad, aluminium-tube.scad, arduino.scad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]
2023-08-27 Add top and bottom arm limiters (#94)
    * restructure frame
    * add limit switch
    * refactor makefile
    * improve apex limit mount
    * add limit switch mount
    * update limit switch mounts
    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
    [__subassembly__.scad, aluminium-tube.scad, apex-limit.scad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]
2023-08-27 Extend foot (#95)
    * extend foot
    * fix render config
    [__subassembly__.scad, foot.scad]
2023-08-27 Add stepper class with acceleration control (#58)
    * write Stepper.tick
    * arduino requirements
    * comment
    * fix build
    * Use AccelStepper library
    * check stepper works
    ---------
    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
    [firmware.ino]
2023-08-27 Add screw to grip arm (#97)
    * add screw
    * add screw
    * update axle and screw
    * place in model
    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
    [__subassembly__.scad, axle-screw.scad, axle-screw.stl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]
2023-08-27 Add phone clamp (#100)
    * add phone clamp
    * add stls
    * update credits
    [__subassembly__.scad, clamp-a.scad, clamp-a.stl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]
2023-09-21 Use state machine library (#103)
    * use state machine library
    * write homing sequence
    * clean up
2023-10-22 Add kicad breakout
    [leo_breakout.kicad_pcb, leo_breakout.kicad_sch]
2024-02-20 Add button class, camera class, stepper settings (#111)
    * button class, camera class, stepper settings, fix scan
    [firmware.ino]
2024-02-20 simplify base (#115)
    [__subassembly__.scad, badge.scad, base-without-badge.scad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]
2024-02-23 add screw to arm motor mount (#117)
    [arm-motor-mount.scad, platform-top.scad]
2024-02-23 add screw to phone mount (#118)
    [gopro-mount.scad]
2024-02-25 fan control (#121)
2024-02-25 add start button behaviour (#122)
2024-02-25 add cable clip (#120)
    [bottom-limit.scad, cable-clip.scad]
2024-03-01 Add pulley (#101)
    [__subassembly__.scad, arm-motor-mount.scad, arm-motor.scad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]
2024-03-01 update control box (#119)
    [__subassembly__.scad, arduino.scad, base-without-badge.scad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]
2024-03-06 generate gerbers (#133)
    [layers.csv, seacal-scanner.kicad_pcb, seacal-scanner.kicad_sch]
2024-03-10 move limit switch (#138)
    [__subassembly__.scad, apex-limit.scad]
2024-03-10 fix motor mount screw hole (#144)
    [arm-motor-mount.scad]
2026-06-10 Add UI and use USB camera (#156)
    [layers.csv, seacal-scanner.kicad_pcb, seacal-scanner.kicad_sch]
